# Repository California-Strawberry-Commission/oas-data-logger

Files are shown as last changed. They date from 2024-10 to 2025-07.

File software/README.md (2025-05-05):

# Operator Aid Systems Data Collection

## Objective

A common, fast and reliable method for data collection for Operator Aid Systems, such as bug vac and spray rig.

We continuously gather data from connected sensors, and save it to an SD card. When connected to WiFi, the data is uploaded to a server. We provide a web-based interface to visualize the data.

## Hardware

The [Adafruit ItsyBitsy ESP32](https://learn.adafruit.com/adafruit-itsybitsy-esp32/overview) was ultimately selected due to its small form factor, relatively large number of GPIO pins, power management, Wi-Fi and Bluetooth capabilities, and I2C connector. We had originally worked with the Sparkfun Thing Plus. However, the ItsyBitsy has a smaller size, extra power management features, and better isolation between the VCC and battery rails. With the Sparkfun Thing Plus, we needed to mod in a better diode onto the board to get USB power detection to work, and found that GPS did not work on I2C (and thus had to use UART).

Relevant features include:

- USB to serial converter chip
- Power regulator
- STEMMA QT I2C connector (which we use for the GPS module)
- Low power (light sleep at 4mA, deep sleep at ~10uA)
- Wi-Fi and Bluetooth
- 20 GPIO pins
- SPI pins (which we use for the MicroSD module)
- User switch
- Small form factor

The GPS module provides support for GPS, GLONASS, GALILEO, and QZSS, providing updates at up to 10 Hz and with both UART and I2C interfaces.

## Software

### ESP32

`oas-logger` is a PlatformIO (IDE for embedded systems, based on VSCode) project for the ESP32 to log data from various attached sensors (currently only GPS) using the Arduino API. It depends on `dlflib`, which is used for writing and uploading log data.

### Server

`data-visualizer` is a Next.js app deployed on Vercel for uploading and visualizing OAS data. It depends on `dlflib-js`, which is used for parsing `.dlf` files, and so we use an npm workspace.

See [README.md](data-visualizer/README.md).

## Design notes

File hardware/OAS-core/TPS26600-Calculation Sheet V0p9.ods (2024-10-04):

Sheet: Calculation Sheet
TPS26600 Design Calculation Tool
Constants Cells | Input/SelectCells | Calculation Cells
 | Calculated, but can be over-ridden by user
Parameter | Description | Value | Units | Tolerance
VIN (max) | Maximum System Input Voltage | 28.00 | V
Uvset | Undervoltage Lockout Threshold | 8.00 | V
OVset | Over Voltage Cut-Off Threshold | 29.00 | V
Cout | Load Capacitance | 220.0 | µF | 10%
TA (max) | Max Ambient Temperature | 85 | °C
RLstart | Load at start-up (assumed to be resistive) | 48.0 | Ω
Imax | Maximum continuous load current | 1.5 | A
ILimit | Current Limit, 20% higher than maximum continuous load current | 1.80 | A
UVLO, OVP Calculations
R3_sel | Select a value in the range from 10k to 49.9k | 10.0 | kΩ | 1% |  |  | 100
R2_cal | Calculated value of Resistor at UVLO pin | 26.3 | kΩ |  | 9.17 | Power Fail (VIN Falling) | 262.5
R1_cal | Calculated value of Resistor at IN pin | 207.4 | kΩ |  | 9.92 | UVLO (VIN Rising) | 207.4
SELECT THE VALUE OF RESISTORS AS CLOSEST AVAILABLE VALUE OF R2,R3 & R8 (refer schematics) |  |  |  |  | 29.75 | OV (VIN Rising)
R3_sel | Select the closest possible value as R3_cal | 10.00 | kΩ | 1% |  |  | 100
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

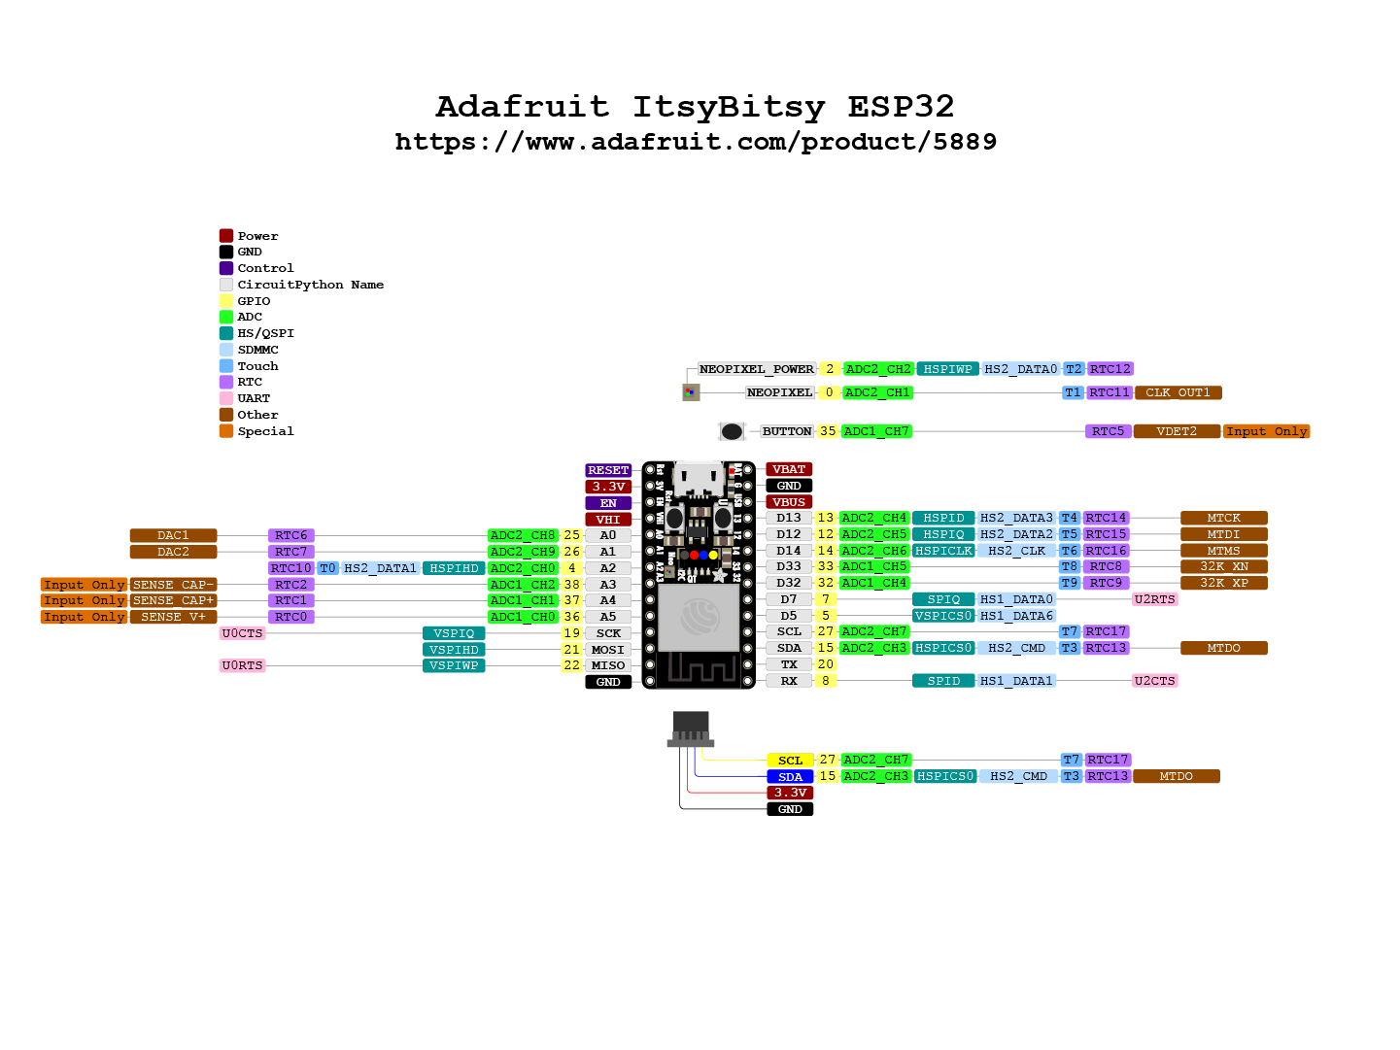
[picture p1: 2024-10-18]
hardware/prototype/adafruit_products_Adafruit_ItsyBitsy_ESP32_PrettyPinsPDF-100.jpg

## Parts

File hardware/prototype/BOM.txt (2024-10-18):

Cart		https://www.digikey.com/short/8qz30pnn

ESP32 		https://www.adafruit.com/product/5889
SD breakout	https://www.adafruit.com/product/4682
Battery		https://www.adafruit.com/product/2750
GPS		https://www.adafruit.com/product/4415
Qwicc conn. 	https://www.adafruit.com/product/4399

Battery Conn.	https://www.digikey.com/en/products/detail/adafruit-industries-llc/2750/6612470

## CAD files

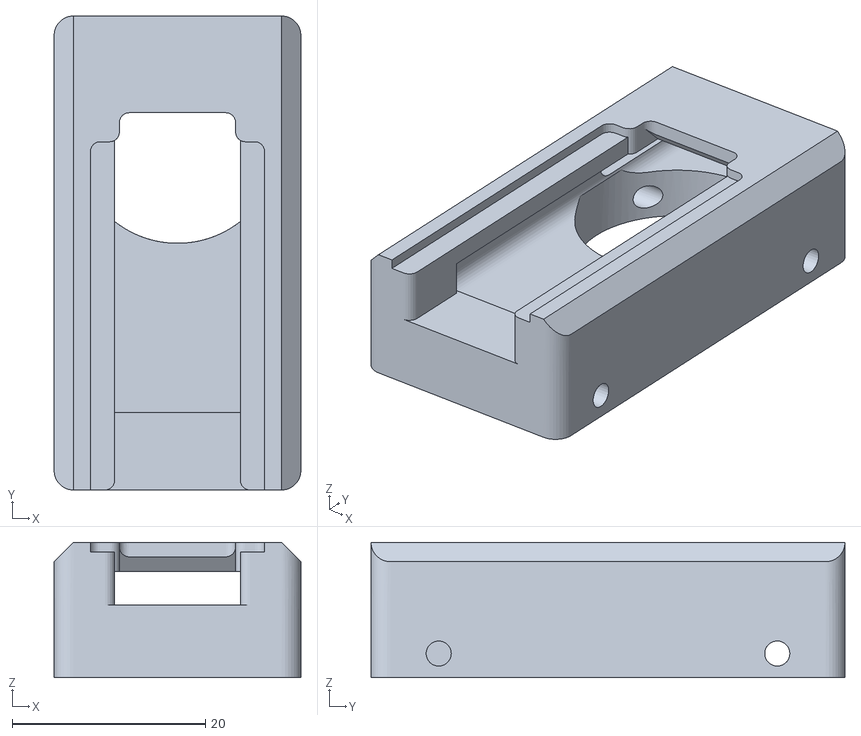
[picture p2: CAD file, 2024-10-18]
hardware/prototype/Carrier.stl
25.5 x 49.0 x 14.0

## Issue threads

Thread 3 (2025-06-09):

Automatically go back to sleep after sync complete

genkikondo, 2025-06-09:
Currently, when the device enters offload mode, it will stay on until either 1) the sleep button is pressed; 2) the reset button is pressed; or 3) the battery runs out. We want the device to go to sleep after syncing is complete, as there is nothing left to do afterwards.

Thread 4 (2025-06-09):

Ensure power draw is minimal in sleep mode

genkikondo, 2025-06-09:
Currently, peripherals (SD card module, GPS module) still draw power even in "deep sleep" mode.
90mA in normal mode (41.4mA without GPS)
80mA in deep sleep mode (31.2mA without GPS - due to MicroSD breakout board)
Figure out how to Ideally we can stay below 1mA in deep sleep mode.

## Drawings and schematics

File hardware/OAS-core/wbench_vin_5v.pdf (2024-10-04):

## WEBENCH ® Design Report

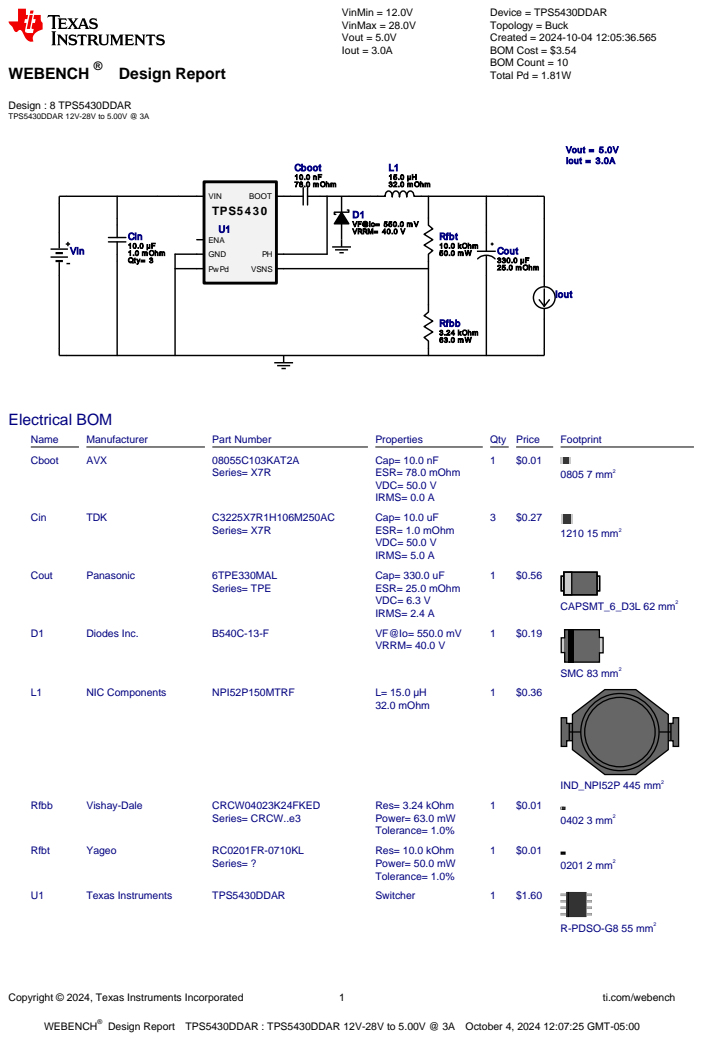
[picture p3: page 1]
Copyright © 2024, Texas Instruments Incorporated; ti.com/webench; WEBENCH®; Design : 8 TPS5430DDAR TPS5430DDAR 12V-28V to 5.00V @ 3A; VinMin = 12.0V VinMax = 28.0V Vout = 5.0V Iout = 3.0A; Device = TPS5430DDAR Topology = Buck Created = 2024-10-04 12:05:36.565 BOM Cost = $3.54 BOM Count = 10 Total Pd = 1.81W; Cboot 10.0 nF 78.0 m Ohm; Cin 10.0 µF 1.0 m Ohm Qty= 3; D1 VF@Io= 550.0 m V VRRM= 40.0 V; L1 15.0 µH 32.0 m Ohm; Rfbb 3.24 kOhm 63.0 m W; Rfbt 10.0 kOhm 50.0 m W; TPS5 4 3 0; ENA; GND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

Design Report TPS5430DDAR : TPS5430DDAR 12V-28V to 5.00V @ 3A October 4, 2024 12:07:25 GMT-05:00

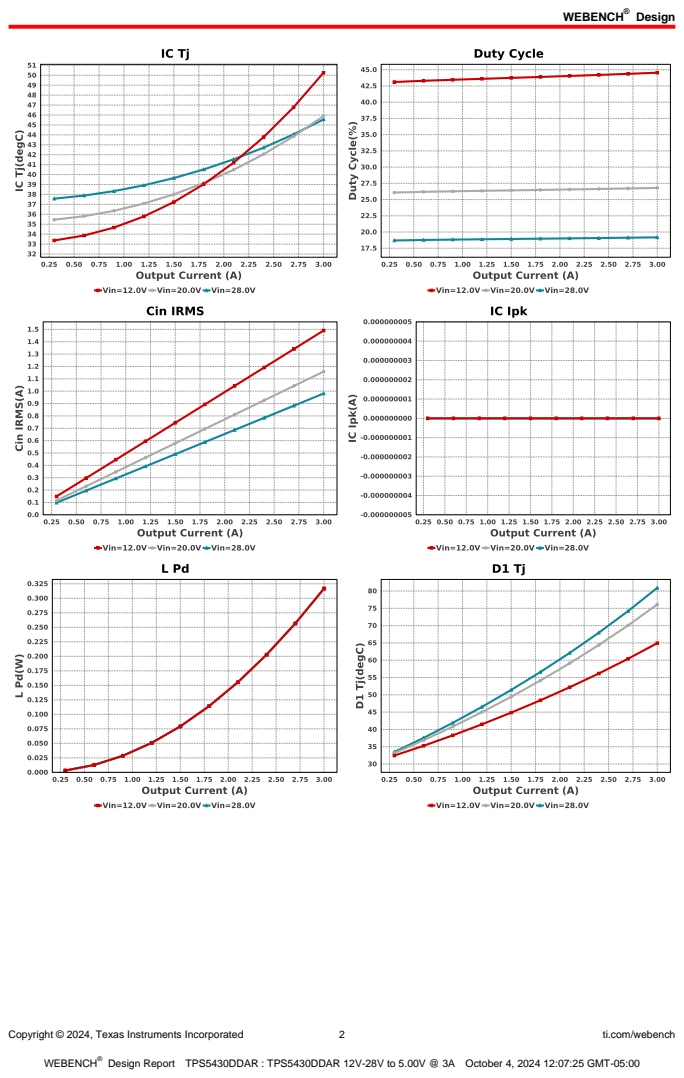
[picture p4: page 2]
Design; Copyright © 2024, Texas Instruments Incorporated; ti.com/webench

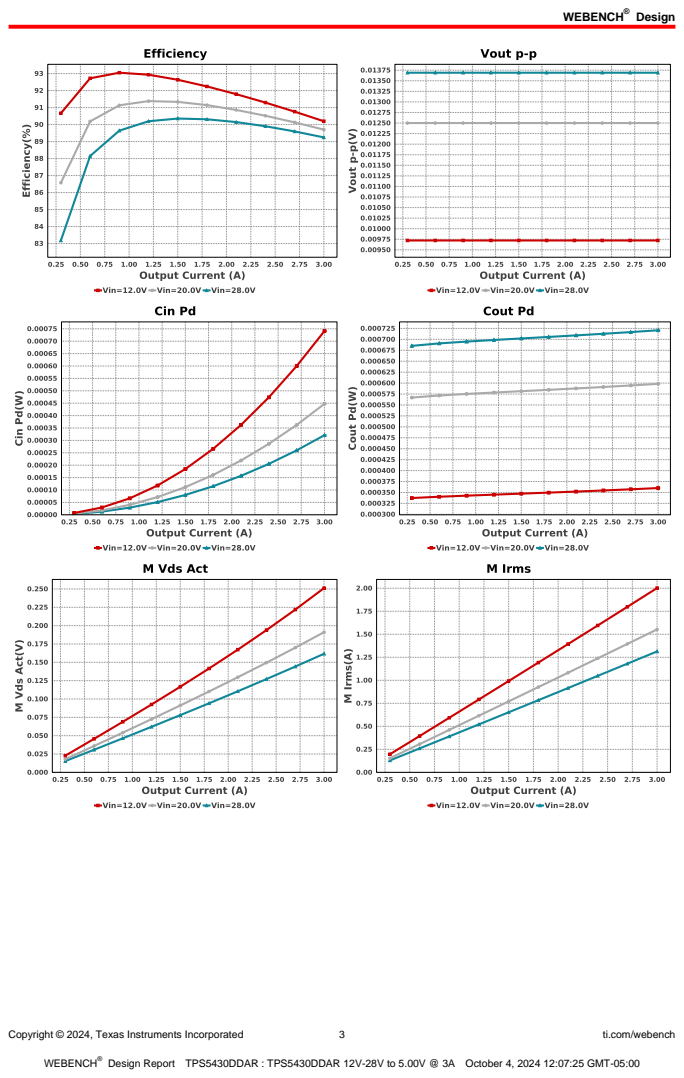
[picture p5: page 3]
Copyright © 2024, Texas Instruments Incorporated; ti.com/webench

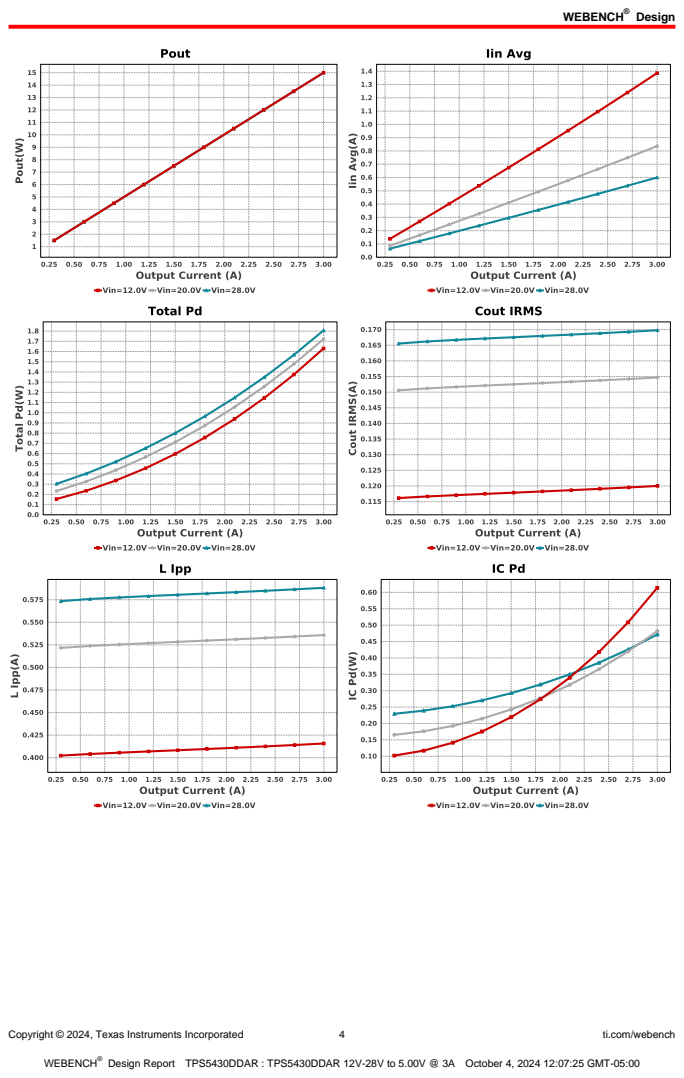
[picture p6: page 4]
Copyright © 2024, Texas Instruments Incorporated; ti.com/webench

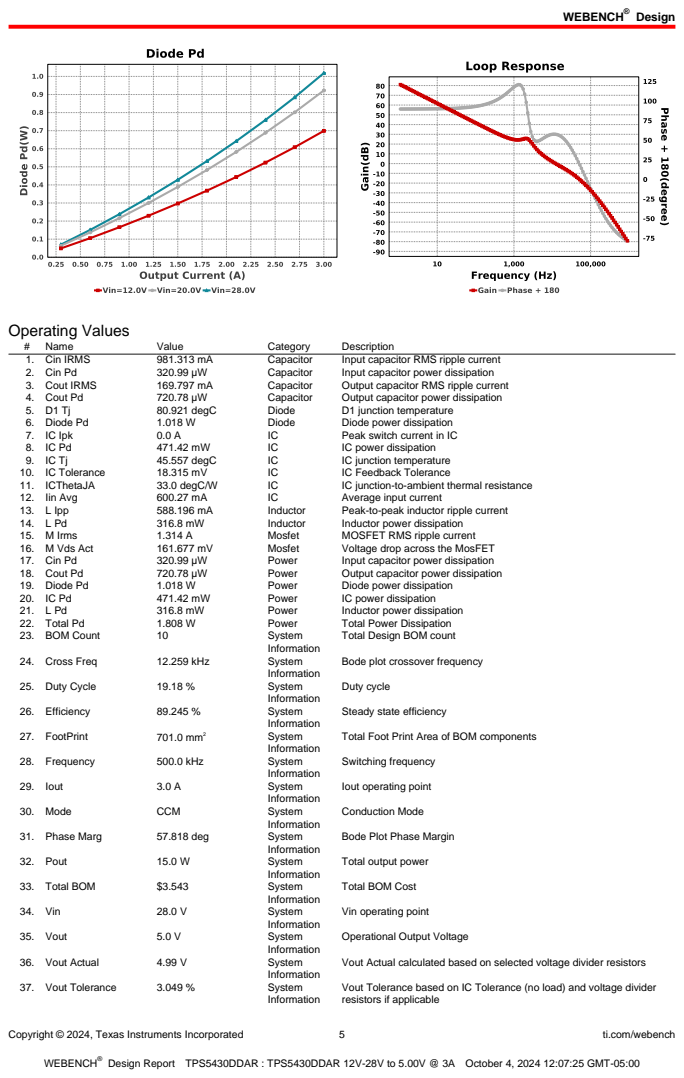
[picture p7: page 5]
Copyright © 2024, Texas Instruments Incorporated; ti.com/webench; Operating Values; Name; Value; Category; Description; 1. Cin IRMS; Capacitor; Input capacitor RMS ripple current; 2. Cin Pd; Input capacitor power dissipation; 3. Cout IRMS; Output capacitor RMS ripple current; 4. Cout Pd; Output capacitor power dissipation; 80.921 degC; Diode; D1 junction temperature; 6. Diode Pd; Diode power dissipation; 7. IC Ipk; Peak switch current in IC; IC power dissipation; 45.557 degC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

Total Design BOM count

Bode plot crossover frequency

Steady state efficiency

Total Foot Print Area of BOM components

Iout operating point

Bode Plot Phase Margin

Total output power

Total BOM Cost

Vin operating point

Operational Output Voltage

Vout Actual calculated based on selected voltage divider resistors

Vout Tolerance based on IC Tolerance (no load) and voltage divider
resistors if applicable

Copyright © 2024, Texas Instruments Incorporated | 6 | ti.com/webench
# | Name | Value | Category | Description

38. Vout p-p | 13.69 mV | System
| | | Information | Peak-to-peak output ripple voltage

## Design Inputs

Name | Value | Description
Iout | 3.0 | Maximum Output Current
VinMax | 28.0 | Maximum input voltage
VinMin | 12.0 | Minimum input voltage
Vout | 5.0 | Output Voltage
| base_pn | | TPS5430 | Base Product Number
source | DC | Input Source Type
Ta | 30.0 | Ambient temperature


Copyright © 2024, Texas Instruments Incorporated | 7 | ti.com/webench

## Assembly

## Component Testing

Some published data on components in datasheets such as Capacitor ESR and Inductor DC resistance is based on conservative values that will guarantee that the components always exceed the specification. For design purposes it is usually better to work with typical values. Since this data is not always available it is a good practice to measure the Capacitance and ESR values of Cin and Cout, and the inductance and DC resistance of L1 before assembly of the board. Any large discrepancies in values should be electrically simulated in WEBENCH to check for instabilities and thermally simulated in WebTHERM to make sure critical temperatures are not exceeded.

## Soldering Component to Board

If board assembly is done in house it is best to tack down one terminal of a component on the board then solder the other terminal. For surface mount parts with large tabs, such as the DPAK, the tab on the back of the package should be pre-tinned with solder, then tacked into place by one of the pins. To solder the tab town to the board place the iron down on the board while resting against the tab, heating both surfaces simultaneously. Apply light pressure to the top of the plastic case until the solder flows around the part and the part is flush with the PCB. If the solder is not flowing around the board you may need a higher wattage iron (generally 25W to 30W is enough).
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

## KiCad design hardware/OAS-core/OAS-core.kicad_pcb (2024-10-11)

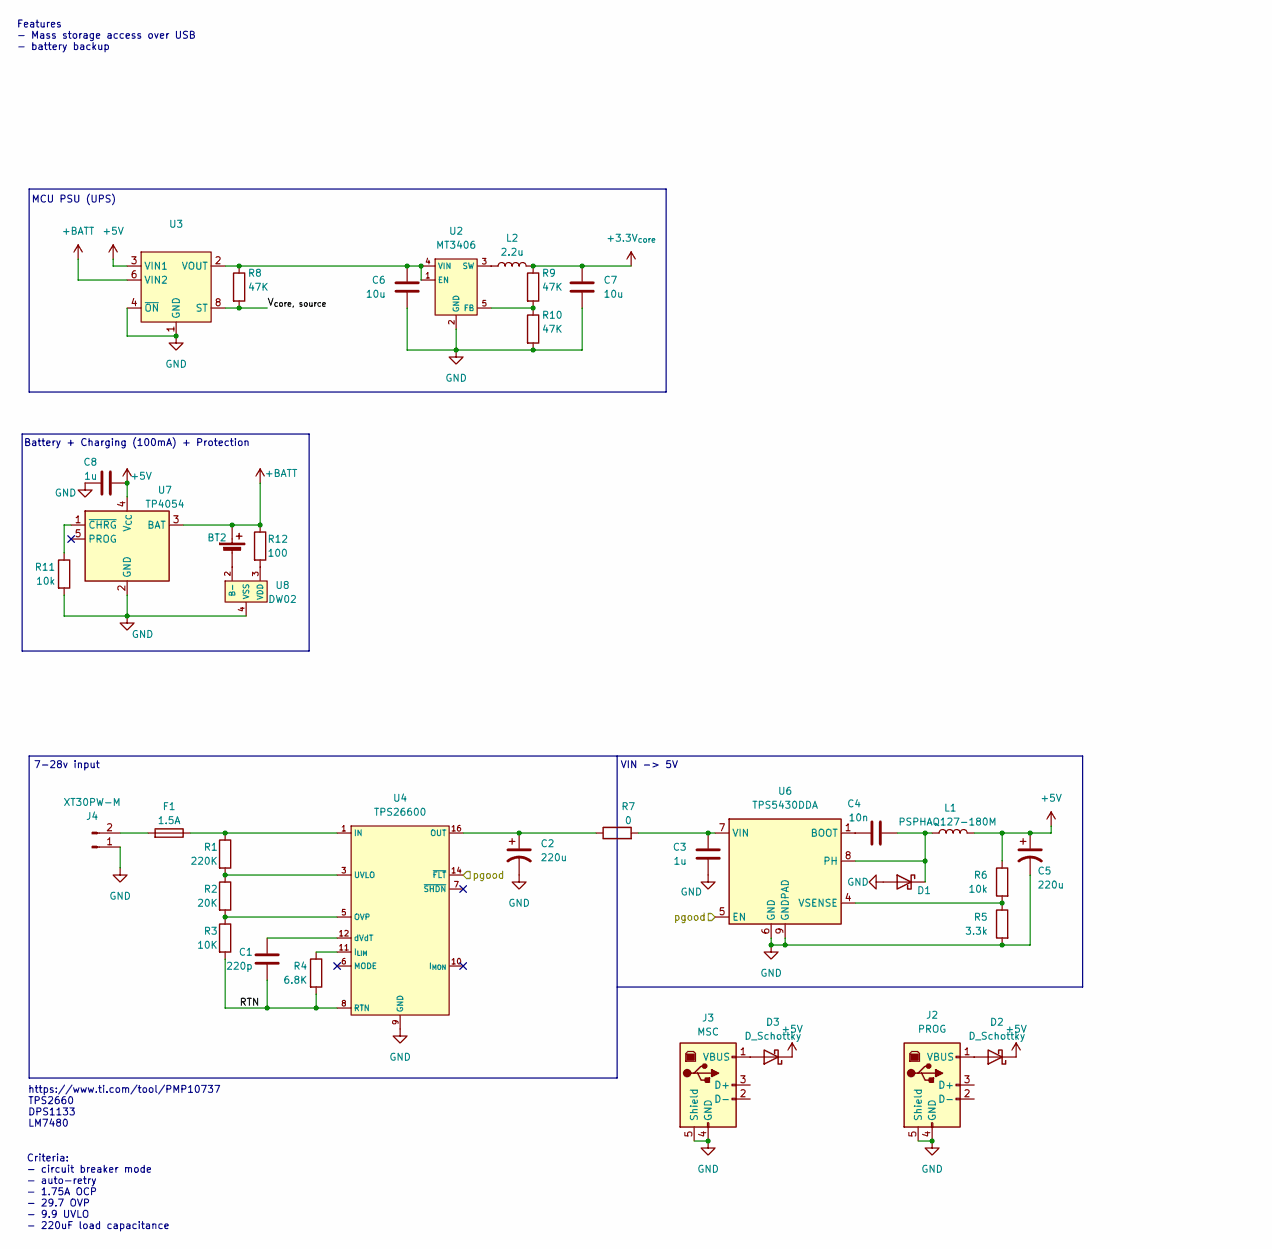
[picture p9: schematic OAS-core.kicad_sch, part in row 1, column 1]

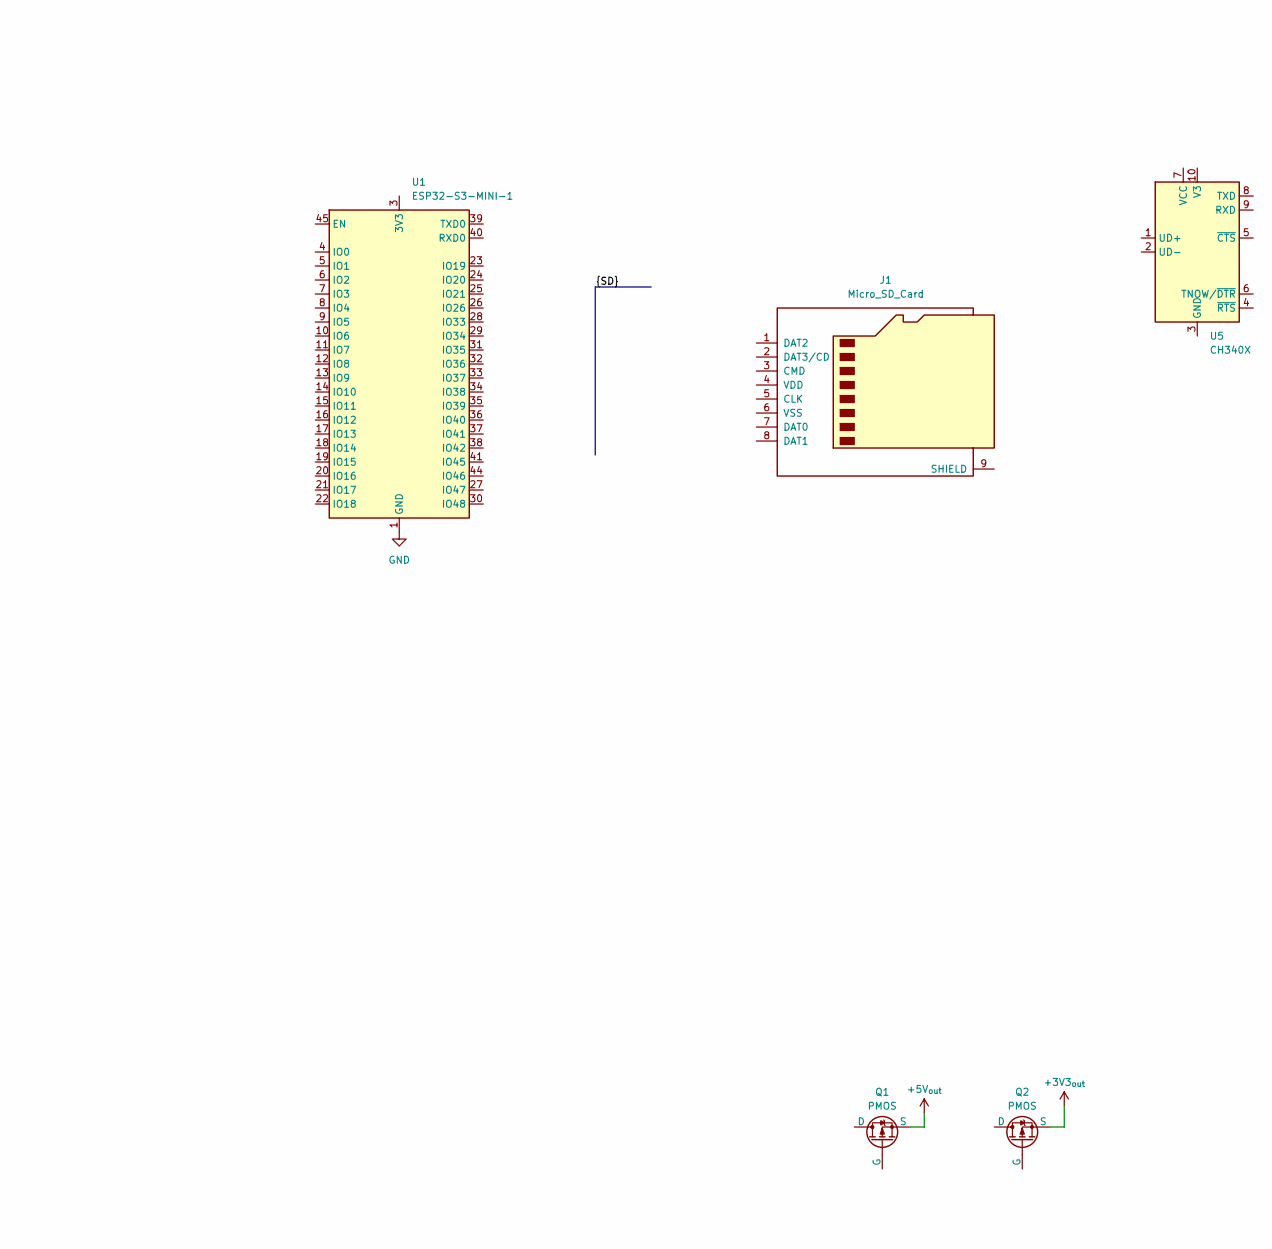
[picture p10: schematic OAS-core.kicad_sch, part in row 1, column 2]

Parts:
BT2: Battery_Cell; JST_PH_B2B-PH-SM4-TB_1x02-1MP_P2.00mm_Vertical
C1: 220p; C_0402_1005Metric
C2: 220u; CP_Elec_8x10.5; LCSC C2983323
C3, C8: 1u; C_0402_1005Metric
C4: 10n; C_0402_1005Metric
C5: 220u; CP_Elec_6.3x5.9; LCSC C2939793
C6, C7: 10u; C_0805_2012Metric; LCSC C15850
D1: D_Schottky; D_SMA; LCSC C7420369
D2, D3: D_Schottky
F1: 1.5A; R_0603_1608Metric; LCSC C2924957
J1: Micro_SD_Card; microSD_HC_Hirose_DM3AT-SF-PEJM5; LCSC C114218
J2: PROG; USB_B_OST_USB-B1HSxx_Horizontal
J3: MSC; USB_B_OST_USB-B1HSxx_Horizontal
J4: XT30PW-M; AMASS_XT30PW-M_1x02_P2.50mm_Horizontal
L1: PSPHAQ127-180M; L_12x12mm_H8mm; LCSC C2983064
L2: 2.2u; L_1008_2520Metric; LCSC C5156791
Q1, Q2: PMOS
R1: 220K; R_0402_1005Metric
R2: 20K; R_0402_1005Metric
R3: 10K; R_0402_1005Metric
R4: 6.8K; R_0402_1005Metric
R5: 3.3k; R_0402_1005Metric; LCSC C25890
R6, R11: 10k; R_0402_1005Metric
R7: 0; R_0402_1005Metric
R8, R9, R10: 47K; R_0402_1005Metric
R12: 100; R_0402_1005Metric
U1: ESP32-S3-MINI-1; ESP32-S2-MINI-1
U2: MT3406; SOT-23-5; LCSC C89358
U3: LM66200; SOT-583-8
U4: TPS26600; HTSSOP-16-1EP_4.4x5mm_P0.65mm_EP3.4x5mm_Mask2.46x2.31mm_The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
U5: CH340X; MSOP-10_3x3mm_P0.5mm
U6: TPS5430DDA; TI_SO-PowerPAD-8_ThermalVias; LCSC C9864
U7: TP4054; TSOT-23-5; LCSC C32574
U8: DW02; SOT-23-5; LCSC C7420470

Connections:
+3.3V_{core}: C7.1, L2.2, R9.1
+5V: C5.1, C8.1, D2.1 (K), D3.1 (K), L1.2, R6.1, U3.3 (VIN1), U7.4 (V_{CC})
+BATT: BT2.1 (+), R12.1, U3.6 (VIN2), U7.3 (BAT)
/RTN: C1.2, R3.2, R4.2, U4.8 (RTN), U4.17 (PAD)
/V_{core, source}: R8.2, U3.8 (ST)
/pgood: U4.14 (~FLT), U6.5 (EN)
GND: C2.2, C3.2, C5.2, C6.2, C7.2, C8.2, D1.2 (A), J2.4 (GND), J2.5 (Shield), J3.4 (GND), J3.5 (Shield), J4.1, R5.2, R10.2, R11.2, U1.1 (GND), U1.2 (GND), U1.42 (GND), U1.43 (GND), U1.46 (GND), U1.47 (GND), U1.48 (GND), U1.49 (GND), U1.50 (GND), U1.51 (GND), U1.52 (GND), U1.53 (GND), U1.54 (GND), U1.55 (GND), U1.56 (GND), U1.57 (GND), U1.58 (GND), U1.59 (GND), U1.60 (GND), U1.61 (GND), U1.62 (GND), U1.63 (GND), U1.64 (GND), U1.65 (GND), U2.2 (GND), U3.1 (GND), U3.4 (~ON), U3.5 (GND), U4.9 (GND), U6.6 (GND), U6.9 (GNDPAD), U7.2 (GND), U8.4 (VSS), U8.5 (VSS)
unnamed: BT2.2 (-), U8.2 (B-)
unnamed: C2.1, R7.1, U4.15 (OUT), U4.16 (OUT)
unnamed: C4.2, D1.1 (K), L1.1, U6.8 (PH)
unnamed: D2.2 (A), J2.1 (VBUS)
unnamed: D3.2 (A), J3.1 (VBUS)
unnamed: F1.1, R1.1, U4.1 (IN), U4.2 (IN)
unnamed: F1.2, J4.2
unnamed: C6.1, R8.1, U2.1 (EN), U2.4 (VIN), U3.2 (VOUT), U3.7 (VOUT)
unnamed: R9.2, R10.1, U2.5 (FB)
unnamed: L2.1, U2.3 (SW)
unnamed: R4.1, U4.11 (I_{LIM})
unnamed: R2.2, R3.1, U4.5 (OVP)
unnamed: R1.2, R2.1, U4.3 (UVLO)
unnamed: C1.1, U4.12 (dVdT)
unnamed: C4.1, U6.1 (BOOT)
unnamed: C3.1, R7.2, U6.7 (VIN)
unnamed: R5.1, R6.2, U6.4 (VSENSE)
unnamed: R11.1, U7.1 (~CHRG)
unnamed: R12.2, U8.3 (VDD)

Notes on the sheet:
VIN -> 5V
Criteria: - circuit breaker mode - auto-retry - 1.75A OCP - 29.7 OVP - 9.9 UVLO - 220uF load capacitance
Battery + Charging (100mA) + Protection
https://www.ti.com/tool/PMP10737 TPS2660 DPS1133 LM7480
7-28v input
MCU PSU (UPS)
Features - Mass storage access over USB - battery backup

Board: 2 copper layers, 37 parts (0 on the bottom side), 24 nets, no tracks yet.

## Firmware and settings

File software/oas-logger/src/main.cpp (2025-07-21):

#include <Arduino.h>
#include <ESP32Time.h>
#include <FastLED.h>
#include <SD.h>
#include <TinyGPSPlus.h>
#include <WiFi.h>
#include <WiFiManager.h>
#include <Wire.h>
#include <freertos/FreeRTOS.h>
#include <freertos/semphr.h>
#include <dlf_logger.h>

// Configuration
const int SERIAL_BAUD_RATE{115200};
const uint32_t LOGGER_MARK_AFTER_UPLOAD{100 * 1024};
const bool LOGGER_DELETE_AFTER_UPLOAD{false};
const bool WAIT_FOR_VALID_TIME{true};
const bool USE_LEGACY_GPIO_CONFIG{true};
const bool USB_POWER_OVERRIDE{false};
const bool USB_POWER_OVERRIDE_VALUE{true};
const int LOGGER_RUN_INTERVAL_S{0};
const int GPS_PRINT_INTERVAL_MS{1000};  

// Pin Definitions
const gpio_num_t PIN_USB_POWER{GPIO_NUM_13};
const gpio_num_t PIN_SLEEP_BUTTON{GPIO_NUM_35};
const gpio_num_t PIN_SD_SCK{USE_LEGACY_GPIO_CONFIG ? GPIO_NUM_8 : GPIO_NUM_19};
const gpio_num_t PIN_SD_MOSI{USE_LEGACY_GPIO_CONFIG ? GPIO_NUM_33 : GPIO_NUM_21};
const gpio_num_t PIN_SD_MISO{USE_LEGACY_GPIO_CONFIG ? GPIO_NUM_32 : GPIO_NUM_22};
const gpio_num_t PIN_SD_CS{GPIO_NUM_14};
const gpio_num_t PIN_GPS_WAKE{GPIO_NUM_5}; // CURRENTLY UNCONNECTED ON PROTOTYPE

// LED Configuration
#define LED_PIN PIN_NEOPIXEL
#define LED_TYPE WS2812
#define LED_COLOR_ORDER GRB
const int NUM_LEDS{1};
const uint8_t LED_BRIGHTNESS{10};

// GPS Configuration
const int I2C_ADDR_GPS{0x10};

// WiFi Configuration 
const char* WIFI_CONFIG_AP_NAME{"OASDataLogger"};
const int WIFI_CONNECT_ATTEMPT_INTERVAL_MS{10000};

// For server hosting
// 1. Uncomment lines below 
// 2. In uploader component, change to WifiClientSecure
const char* UPLOAD_HOST{"oas-data-logger.vercel.app"};
const uint16_t UPLOAD_PORT{443};

// For local hosting:
// 1. Uncomment the lines below
// 2. Go to uploader_component.cpp and change from WiFiClientSecure to WiFiClient.
//const char* UPLOAD_HOST{"192.168.1.129"};  // Your computer's local IP
//const uint16_t UPLOAD_PORT{3000};

// State Machine States
enum class SystemState {
  INIT,
  WAIT_SD,
  WAIT_WIFI,
  WAIT_GPS,
  WAIT_TIME,
  RUNNING,
  OFFLOAD,
  ERROR,
  SLEEP
};

// Error Types for LED Patterns
enum class ErrorType {
  NONE,
  SD_INIT_FAILED,
  GPS_NOT_RESPONDING,
  I2C_INIT_FAILED,
  WIFI_CONFIG_FAILED,
  LOGGER_INIT_FAILED
};

// Global Objects
CRGB leds[NUM_LEDS];
TinyGPSPlus gps;
ESP32Time rtc;
WiFiManager wifiManager;
CSCLogger logger{SD};
TaskHandle_t xGPS_Handle;

// State Machine Variables
SystemState currentState = SystemState::INIT;
ErrorType currentError = ErrorType::NONE;
bool offloadMode = false;
bool gpsEnabled = false;
run_handle_t runHandle{0};

// Timing Variables
unsigned long lastWifiReconnectAttemptMillis{0};
unsigned long lastLoggerStartRunMillis{0};
unsigned long lastLedToggleMillis{0};
unsigned long lastGpsPrintMillis{0};
bool ledToggleState = false;

// GPS Data Structure with Mutex Protection
struct GpsData {
  double lat;
  double lng;
  double alt;
  uint32_t satellites;
};

GpsData gpsData{0.0, 0.0, 0.0, 0};
SemaphoreHandle_t gpsDataMutex;

// Function Prototypes
void initializeLeds();
void updateLedPattern();
void transitionToState(SystemState newState);
void handleInitState();
void handleWaitSdState();
void handleWaitWifiState();
void handleWaitGpsState();
void handleWaitTimeState();
void handleRunningState();
void handleOffloadState();
void handleErrorState();
void handleSleepState();
bool hasUsbPower();
bool wifiCredentialsExist();
void enableGps();
void disableGps();
void initializeLogger();
void startLoggerRun();
void gpsTask(void* args);
void sleepMonitorTask(void* args);
void testNetworkConnectivity(void);

void setup() {
  Serial.begin(SERIAL_BAUD_RATE);
  
  // Initialize LED first for status indication
  initializeLeds();
  
  // Create mutex for GPS data protection
  gpsDataMutex = xSemaphoreCreateMutex();
  if (gpsDataMutex == NULL) {
    currentError = ErrorType::LOGGER_INIT_FAILED;
    transitionToState(SystemState::ERROR);
    return;
  }
  
  // Configure pins
  pinMode(PIN_USB_POWER, INPUT_PULLDOWN);
  pinMode(PIN_SLEEP_BUTTON, INPUT_PULLUP);
  pinMode(PIN_GPS_WAKE, OUTPUT);
  
  // Add delay to give time for serial to initialize
  vTaskDelay(pdMS_TO_TICKS(1000));
  
  // Start sleep monitor task
  xTaskCreate(sleepMonitorTask, "sleep_monitor", 4096, NULL, 5, NULL);
  
  // Determine initial mode based on USB power
  offloadMode = !hasUsbPower();
  
  // Start state machine
  transitionToState(SystemState::INIT);
}

void loop() {
  // Update LED pattern based on current state
  updateLedPattern();
  
  // State machine logic
  switch (currentState) {
    case SystemState::INIT:
      handleInitState();
      break;
    case SystemState::WAIT_SD:
      handleWaitSdState();
      break;
    case SystemState::WAIT_WIFI:
      handleWaitWifiState();
      break;
    case SystemState::WAIT_GPS:
      handleWaitGpsState();
      break;
    case SystemState::WAIT_TIME:
      handleWaitTimeState();
      break;
    case SystemState::RUNNING:
      handleRunningState();
      break;
    case SystemState::OFFLOAD:
      handleOffloadState();
      break;
    case SystemState::ERROR:
      handleErrorState();
      break;
    case SystemState::SLEEP:
      handleSleepState();
      break;
  }
  
  vTaskDelay(pdMS_TO_TICKS(10));
}

void initializeLeds() {
  FastLED.addLeds<LED_TYPE, LED_PIN, LED_COLOR_ORDER>(leds, NUM_LEDS);
  FastLED.setBrightness(LED_BRIGHTNESS);
  FastLED.showColor(CRGB::White);
}

void updateLedPattern() {
  unsigned long currentMillis = millis();
  
  switch (currentState) {
    case SystemState::INIT:
      FastLED.showColor(CRGB::White);
      break;
      
    case SystemState::WAIT_SD:
    case SystemState::WAIT_WIFI:
    case SystemState::WAIT_GPS:
    case SystemState::WAIT_TIME:
      // Yellow blinking for waiting states
      if (currentMillis - lastLedToggleMillis > 500) {
        lastLedToggleMillis = currentMillis;
        ledToggleState = !ledToggleState;
        FastLED.showColor(ledToggleState ? CRGB::Yellow : CRGB::Black);
      }
      break;
      
    case SystemState::RUNNING:
      FastLED.showColor(CRGB::Green);
      break;
      
    case SystemState::OFFLOAD:
      FastLED.showColor(CRGB::Blue);
      break;
      
    case SystemState::ERROR:
      // Different blink patterns for different errors
      uint32_t blinkInterval;
      switch (currentError) {
        case ErrorType::SD_INIT_FAILED:
          blinkInterval = 200; // Fast blink
          break;
        case ErrorType::GPS_NOT_RESPONDING:
          blinkInterval = 400; // Medium blink
          break;
        case ErrorType::I2C_INIT_FAILED:
          blinkInterval = 600; // Slow blink
          break;
        case ErrorType::WIFI_CONFIG_FAILED:
          blinkInterval = 800; // Very slow blink
          break;
        default:
          blinkInterval = 1000; // Default slow blink
          break;
      }
      
      if (currentMillis - lastLedToggleMillis > blinkInterval) {
        lastLedToggleMillis = currentMillis;
        ledToggleState = !ledToggleState;
        FastLED.showColor(ledToggleState ? CRGB::Red : CRGB::Black);
      }
      break;
      
    case SystemState::SLEEP:
      FastLED.showColor(CRGB::Black);
      break;
  }
}

void transitionToState(SystemState newState) {
  Serial.printf("State transition: %d -> %d\n", (int)currentState, (int)newState);
  currentState = newState;
  
  // Reset LED toggle state on transition
  ledToggleState = false;
  lastLedToggleMillis = millis();
}

void handleInitState() {
  if (offloadMode) {
    transitionToState(SystemState::WAIT_SD);
  } else {
    transitionToState(SystemState::WAIT_SD);
  }
}

void handleWaitSdState() {
  Serial.println("Initializing SPI for SD card...");

  SPI.setFrequency(1000000);
  SPI.setDataMode(SPI_MODE0);

  SPI.begin(PIN_SD_SCK, PIN_SD_MISO, PIN_SD_MOSI, PIN_SD_CS); // No return value to check

  if (SD.begin(PIN_SD_CS)) {
    Serial.println("SD card connected");
    transitionToState(SystemState::WAIT_WIFI);
  }

  // Keep trying, no immediate error transition
}

void handleWaitWifiState() {
  Serial.println("Initializing WiFi...");
  WiFi.mode(WIFI_STA);
  wifiManager.setConfigPortalBlocking(true);

  bool hasCreds = wifiCredentialsExist();

  if (offloadMode) {
    if (hasCreds) {
      Serial.println("Offload mode with credentials, attempting to connect indefinitely...");
      WiFi.begin();
      while (WiFi.status() != WL_CONNECTED) {
        Serial.println("Waiting for WiFi (offload mode)...");
        delay(1000);
      }
      Serial.println("Connected to WiFi.");
      testNetworkConnectivity();
      transitionToState(SystemState::OFFLOAD);
    } else {
      Serial.println("Offload mode with no credentials, entering AP mode indefinitely...");
      wifiManager.setConfigPortalTimeout(0); // Block until credentials provided
      if (!wifiManager.autoConnect(WIFI_CONFIG_AP_NAME)) {
        currentError = ErrorType::WIFI_CONFIG_FAILED;
        transitionToState(SystemState::ERROR);
        return;
      }
      Serial.println("Credentials acquired in AP mode.");
      transitionToState(SystemState::OFFLOAD);
    }
  } else {
    if (hasCreds) {
      Serial.println("Normal mode with credentials, attempting connection...");
      WiFi.begin();
      unsigned long startAttempt = millis();
      while (WiFi.status() != WL_CONNECTED && millis() - startAttempt < 10000) {
        delay(500);
        Serial.print(".");
      }

      if (WiFi.status() == WL_CONNECTED) {
        Serial.println("\nConnected to WiFi.");
        testNetworkConnectivity();
        transitionToState(SystemState::WAIT_GPS);
      } else {
        Serial.println("\nConnection failed, entering AP mode for 3 minutes...");
        wifiManager.setConfigPortalTimeout(180); // 3 minutes
        wifiManager.startConfigPortal(WIFI_CONFIG_AP_NAME);
        Serial.println("Exiting AP mode (timeout or user finished). Continuing program.");
        transitionToState(SystemState::WAIT_GPS); // Proceed regardless of connection
      }
    } else {
      Serial.println("No credentials, waiting in AP mode until provided...");
      wifiManager.setConfigPortalTimeout(0); // No timeout
      if (!wifiManager.autoConnect(WIFI_CONFIG_AP_NAME)) {
        currentError = ErrorType::WIFI_CONFIG_FAILED;
        transitionToState(SystemState::ERROR);
        return;
      }
      Serial.println("Credentials acquired in AP mode.");
      transitionToState(SystemState::WAIT_GPS);
    }
  }

  if (WiFi.status() == WL_CONNECTED) {
    testNetworkConnectivity();
  }
}

void handleWaitGpsState() {
  if (offloadMode) {
    // Skip GPS in offload mode
    transitionToState(SystemState::OFFLOAD);
    return;
  }
  
  enableGps();
  
  if (gpsEnabled) {
    // Start GPS task
    xTaskCreate(gpsTask, "gps", 4096, NULL, 5, &xGPS_Handle);
    transitionToState(SystemState::WAIT_TIME);
  }
}

void handleWaitTimeState() {
  // Try to get GPS data with mutex protection
  if (xSemaphoreTake(gpsDataMutex, portMAX_DELAY) == pdTRUE) {
    // Check if we have valid time
    if (gps.date.isUpdated() && gps.date.isValid() && 
        gps.time.isUpdated() && gps.time.isValid() && 
        gps.location.age() < 2000 && gps.date.year() >= 2025) {
      
      rtc.setTime(gps.time.second(), gps.time.minute(), gps.time.hour(),
                  gps.date.day(), gps.date.month(), gps.date.year());
      Serial.println("Valid time received");
      
      xSemaphoreGive(gpsDataMutex);
      
      // Initialize logger and start run
      initializeLogger();
      startLoggerRun();
      transitionToState(SystemState::RUNNING);
    } else {
      xSemaphoreGive(gpsDataMutex);
    }
  }
}

void handleRunningState() {
  // WiFi reconnection logic
  if (millis() - lastWifiReconnectAttemptMillis > WIFI_CONNECT_ATTEMPT_INTERVAL_MS) {
    if (WiFi.status() != WL_CONNECTED) {
      Serial.println("WiFi not connected, retrying...");
      WiFi.begin();
      lastWifiReconnectAttemptMillis = millis();
    } else {
      // Upload the current run over wifi
      static unsigned long lastUploadAttemptMillis = 0;
      const unsigned long UPLOAD_ATTEMPT_INTERVAL_MS = 30000; // Try upload every 30s when connected
      
      if (millis() - lastUploadAttemptMillis > UPLOAD_ATTEMPT_INTERVAL_MS) {
        lastUploadAttemptMillis = millis();
        
        if (runHandle) {
          // Get the current run directory name
          // The run name format appears to be based on when start_run was called
          // We need to access the logger's current run directory
          
          Serial.println("[Running State] Attempting to upload current run while logging...");

          UploaderComponent::Options tempOptions;
          tempOptions.deleteAfterUpload = false;
          tempOptions.markAfterUpload = false;
          
          // Create a temporary uploader instance for the current run
          UploaderComponent tempUploader(SD, "/", UPLOAD_HOST, UPLOAD_PORT, tempOptions);
          
          // The logger stores runs in the root directory with a specific naming convention
          // We need to find the current run directory
          File root = SD.open("/");
          if (root) {
            File runDir;
            String currentRunPath;
            
            // Find the most recent run directory (which should be our current run)
            // Run directories don't have the lockfile when complete, but our current run
            // should still have it
            while (runDir = root.openNextFile()) {
              if (runDir.isDirectory() && runDir.name()[0] != '.' &&
                  strcmp(runDir.name(), "System Volume Information") != 0) {
                
                // Check if this directory has a lockfile (indicating active run)
                File lockCheck = SD.open(String("/") + runDir.name() + "/" + LOCKFILE_NAME);
                if (lockCheck) {

                  lockCheck.close();
                  currentRunPath = String("/") + runDir.name();
                  Serial.printf("[Running State] Found active run: %s\n", runDir.name());

                  Serial.println("[Running State] Flushing data and finalizing headers for upload...");
                  logger.flush(runHandle); 

                  // Upload this run
                  String uploadPath = String("/api/upload/") + runDir.name();
                  bool uploadSuccess = tempUploader.uploadRun(runDir, uploadPath);

                  if (uploadSuccess) {
                    Serial.println("[Running State] Successfully uploaded current run data");
                    // Note: We don't mark or delete the run since it's still active
                  } else {
                    Serial.println("[Running State] Failed to upload current run data");
                  }
                  
                  break; // We found and processed the current run
                }
              }
            }
            root.close();
          }
        }
      }
    } 
  }
  
  // GPS printing logic - independent of logger run interval
  if (millis() - lastGpsPrintMillis > GPS_PRINT_INTERVAL_MS) {
    lastGpsPrintMillis = millis();
    
    // Try to get GPS data with mutex protection
    if (xSemaphoreTake(gpsDataMutex, pdMS_TO_TICKS(100)) == pdTRUE) {
      Serial.printf("[GPS] Lat: %.6f, Lng: %.6f, Alt: %.1fm, Sats: %d\n", 
                    gpsData.lat, gpsData.lng, gpsData.alt, gpsData.satellites);
      xSemaphoreGive(gpsDataMutex);
    }
  }
  
  // Run interval logic - only if LOGGER_RUN_INTERVAL_S > 0
  if (runHandle && LOGGER_RUN_INTERVAL_S > 0 &&
      millis() - lastLoggerStartRunMillis > LOGGER_RUN_INTERVAL_S * 1000) {
    startLoggerRun();
  }
}

void handleOffloadState() { 
  // Give logger sync/upload time to start
  vTaskDelay(pdMS_TO_TICKS(100));
  
  logger.waitForSyncCompletion();
  
  // After sync completion, either sleep or continue
  transitionToState(SystemState::SLEEP);
}

void handleErrorState() {
  // Error state is handled by LED pattern
  // Could add recovery logic here if needed
  
  // Log error details
  Serial.printf("System in ERROR state. Error type: %d\n", (int)currentError);
  
  // For critical errors, restart after 10 seconds
  static unsigned long errorStartMillis = millis();
  if (millis() - errorStartMillis > 10000) {
    ESP.restart();
  }
}

void handleSleepState() {
  Serial.println("Entering deep sleep...");
  
  // Stop all tasks
  disableGps();
  
  // Turn off LED
  FastLED.showColor(CRGB::Black);
  
  // Configure wake on USB power only if unconnected, else wake on reset.
  if (!hasUsbPower()) {
    esp_sleep_enable_ext0_wakeup(PIN_USB_POWER, 1);
  } else {
    esp_sleep_disable_wakeup_source(ESP_SLEEP_WAKEUP_ALL);
  }
  
  // Enter deep sleep
  esp_deep_sleep_start();
}

bool hasUsbPower() {
  if (USB_POWER_OVERRIDE) {
    return USB_POWER_OVERRIDE_VALUE;
  }
  return digitalRead(PIN_USB_POWER);
}

bool wifiCredentialsExist() {
  wifi_config_t conf;
  esp_err_t result = esp_wifi_get_config(WIFI_IF_STA, &conf);
  
  if (result != ESP_OK) {
    Serial.printf("esp_wifi_get_config failed: %d\n", result);
    return false;
  }
  
  return strlen((const char*)conf.sta.ssid) > 0;
}

void enableGps() {
  if (gpsEnabled) {
    return;
  }
  
  Serial.println("Enabling GPS...");
  
  // Initialize I2C
  if (!Wire.begin()) {
    currentError = ErrorType::I2C_INIT_FAILED;
    transitionToState(SystemState::ERROR);
    return;
  }
  
  // Activate wake pin
  digitalWrite(PIN_GPS_WAKE, HIGH);
  
  // Wait for GPS to respond
  bool gpsResponding = false;
  int attempts = 0;
  const int maxAttempts = 10;
  
  while (!gpsResponding && attempts < maxAttempts) {
    Wire.requestFrom(I2C_ADDR_GPS, 32);
    while (Wire.available()) {
      char c = Wire.read();
      gps.encode(c);
      gpsResponding = true;
    }
    
    if (!gpsResponding) {
      attempts++;
      vTaskDelay(pdMS_TO_TICKS(500));
    }
  }
  
  if (!gpsResponding) {
    currentError = ErrorType::GPS_NOT_RESPONDING;
    transitionToState(SystemState::ERROR);
    return;
  }
  
  digitalWrite(PIN_GPS_WAKE, LOW);
  gpsEnabled = true;
  Serial.println("GPS enabled");
}

void disableGps() {
  if (!gpsEnabled) {
    return;
  }
  
  Serial.println("Disabling GPS...");

  // Check if the task handle is valid
  if (gpsTask != NULL)
  {
      Serial.println("[GPS] Deleting GPS task...");
      // Delete the task
      vTaskDelete(xGPS_Handle);
  }
  
  // Put GPS in Backup Mode
  if (!USE_LEGACY_GPIO_CONFIG) {
    Wire.beginTransmission(I2C_ADDR_GPS);
    Wire.write("$PMTK225,4*2F\r\n");
    Wire.endTransmission();
  }
  
  // Close I2C
  Wire.end();
  
  gpsEnabled = false;
  Serial.println("GPS disabled");
}

void initializeLogger() {
  Serial.println("Initializing logger...");
  
  auto satellitesLogInterval{std::chrono::seconds(5)};
  POLL(logger, gpsData.satellites, satellitesLogInterval);
  
  auto gpsDataLogInterval{std::chrono::seconds(1)};
  POLL(logger, gpsData.lat, gpsDataLogInterval);
  POLL(logger, gpsData.lng, gpsDataLogInterval);
  POLL(logger, gpsData.alt, gpsDataLogInterval);
  
  UploaderComponent::Options options;
  options.markAfterUpload = LOGGER_MARK_AFTER_UPLOAD;
  options.deleteAfterUpload = LOGGER_DELETE_AFTER_UPLOAD;
  logger.syncTo(UPLOAD_HOST, UPLOAD_PORT, options).begin();
  
  Serial.println("Logger initialized");
}

void startLoggerRun() {
  if (runHandle) {
    logger.stop_run(runHandle);
  }
  
  double m = 0;
  runHandle = logger.start_run(Encodable(m, "double"));
  lastLoggerStartRunMillis = millis();
}

void gpsTask(void* args) {
  while (true) {
    // Request data from GPS
    Wire.requestFrom(I2C_ADDR_GPS, 32);
    
    // Process received data
    while (Wire.available()) {
      char c = Wire.read();
      gps.encode(c);
    }
    
    // Update GPS data with mutex protection
    if (xSemaphoreTake(gpsDataMutex, portMAX_DELAY) == pdTRUE) {
      // Make sure the data will be valid
      if (gps.satellites.isUpdated() && gps.satellites.isValid() && gps.satellites.value() != 0 ) {
        gpsData.satellites = gps.satellites.value();

        if (gps.location.isUpdated() && gps.location.isValid()) {
          gpsData.lat = gps.location.lat();
          gpsData.lng = gps.location.lng();
          gpsData.alt = gps.altitude.meters();
        }
      }
      xSemaphoreGive(gpsDataMutex);
    }
    
    vTaskDelay(pdMS_TO_TICKS(100));
  }
}

void sleepMonitorTask(void* args) {
  vTaskDelay(pdMS_TO_TICKS(5000));
  
  bool usbSleepTriggered = false;
  
  while (true) {
    // Only check sleep conditions if we're in RUNNING state
    if (currentState == SystemState::RUNNING) {
      // Check sleep button
      bool sleepButtonPressed = !digitalRead(PIN_SLEEP_BUTTON);
      if (sleepButtonPressed) {
        Serial.println("[Sleep Monitor] Sleep button pressed. Starting offload before sleep");
        
        // Stop current run before transitioning to offload
        if (runHandle) {
          logger.stop_run(runHandle);
          runHandle = 0;
        }
        
        transitionToState(SystemState::OFFLOAD);
        break;
      }
      
      // Check USB power for sleep trigger
      bool usbSleep = !offloadMode && !hasUsbPower();
      if (usbSleep && usbSleepTriggered) {
        Serial.println("[Sleep Monitor] USB power disconnected. Starting offload before sleep");
        
        // Stop current run before transitioning to offload
        if (runHandle) {
          logger.stop_run(runHandle);
          runHandle = 0;
        }
        
        transitionToState(SystemState::OFFLOAD);
        break;
      } else if (usbSleep) {
        usbSleepTriggered = true;
      } else {
        usbSleepTriggered = false;
      }
    }
    
    vTaskDelay(pdMS_TO_TICKS(1000));
  }
  
  // Task will be deleted when system enters sleep
  vTaskDelete(NULL);
}
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

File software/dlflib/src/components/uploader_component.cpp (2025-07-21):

#include "uploader_component.h"

#include <WiFiClientSecure.h>
#include <WiFiClient.h>

#include "dlf_cfg.h"
#include "dlf_logger.h"

UploaderComponent::UploaderComponent(FS &fs, String fsDir, String host,
                                     uint16_t port, const Options &options)
    : fs_(fs), dir_(fsDir), host_(host), port_(port), options_(options) {}

bool UploaderComponent::begin() {
  Serial.println("[UploaderComponent] begin");
  wifiEvent_ = xEventGroupCreate();
  syncEvent_ = xEventGroupCreate();

  // Initial states
  if (WiFi.status() == WL_CONNECTED) {
    xEventGroupSetBits(wifiEvent_, WLAN_READY);
  } else {
    xEventGroupClearBits(wifiEvent_, WLAN_READY);
  }
  xEventGroupSetBits(syncEvent_, SYNC_COMPLETE);

  // State change callbacks
  WiFi.onEvent(std::bind(&UploaderComponent::onWifiDisconnected, this,
                         std::placeholders::_1, std::placeholders::_2),
               ARDUINO_EVENT_WIFI_STA_DISCONNECTED);
  WiFi.onEvent(std::bind(&UploaderComponent::onWifiConnected, this,
                         std::placeholders::_1, std::placeholders::_2),
               ARDUINO_EVENT_WIFI_STA_GOT_IP);

  xTaskCreate(syncTask, "sync", 4096, this, 5, NULL);

  return true;
}

void UploaderComponent::onWifiDisconnected(arduino_event_id_t event,
                                           arduino_event_info_t info) {
  Serial.println("[UploaderComponent] WiFi disconnected");
  xEventGroupClearBits(wifiEvent_, WLAN_READY);
}

void UploaderComponent::onWifiConnected(arduino_event_id_t event,
                                        arduino_event_info_t info) {
  Serial.println("[UploaderComponent] WiFi connected");
  xEventGroupSetBits(wifiEvent_, WLAN_READY);
}

bool UploaderComponent::uploadRun(File runDir, String path) {
  //WiFiClient client; 
  WiFiClientSecure client;
  client.setInsecure();
  
  Serial.println("\n=== UPLOAD DEBUG INFO ===");
  Serial.printf("Host: %s\n", host_.c_str());
  Serial.printf("Port: %d\n", port_);
  Serial.printf("Path: %s\n", path.c_str());
  Serial.printf("URL: http://%s:%d%s\n", host_.c_str(), port_, path.c_str());

  if (!runDir) {
    Serial.println("[UploaderComponent] No file to upload");
    return false;
  }

  // List files to be uploaded
  Serial.println("Files to upload:");
  runDir.rewindDirectory();
  File tempFile;
  while (tempFile = runDir.openNextFile()) {
    Serial.printf("  - %s (%d bytes)\n", tempFile.name(), tempFile.size());
    tempFile.close();
  }

  // Try to connect
  Serial.printf("Attempting connection to %s:%d...\n", host_.c_str(), port_);
  
  for (int retries = 0; retries < 3; retries++) {
    if (client.connect(host_.c_str(), port_)) {
      Serial.println("Connected successfully!");
      break;
    }
    Serial.printf("Connection attempt %d failed. ", retries + 1);
    if (retries < 2) {
      Serial.println("Retrying in 1s...");
      vTaskDelay(pdMS_TO_TICKS(1000));
    }
  }

  if (!client.connected()) {
    Serial.println("[UploaderComponent] Failed to connect after 3 attempts.");
    return false;
  }

  // Create request
  // Note that we need to manually construct the multipart/form-data body, and
  // each file must be streamed (avoid fully loading into memory)
  const char *boundary = "dlfboundary";
  const char *boundaryTemplate =
      "--dlfboundary\r\n"
      "Content-Disposition: form-data; name=\"files\"; filename=\"%s\"\r\n"
      "Content-Type: application/octet-stream\r\n\r\n";
  const char *endBoundary = "--dlfboundary--\r\n";

  // First, calculate the content length (which needs to go into the request
  // header)
  size_t contentLength = 0;
  runDir.rewindDirectory();
  File file = runDir.openNextFile();
  while (file) {
    contentLength += snprintf(NULL, 0, boundaryTemplate, file.name());
    contentLength += file.size();
    contentLength += 2;  // for trailing \r\n after file content
    file.close();
    file = runDir.openNextFile();
  }
  contentLength += strlen(endBoundary);

  // Debug print out header information.
  Serial.println("\n=== HTTP REQUEST ===");
  Serial.printf("POST %s HTTP/1.1\r\n", path.c_str());
  Serial.printf("Host: %s\r\n", host_.c_str());
  Serial.printf("Content-Type: multipart/form-data; boundary=dlfboundary\r\n");
  Serial.printf("Content-Length: %zu\r\n", contentLength);
  Serial.println("Connection: close\r\n");
  Serial.println("===================\n");

  // Send POST request header
  Serial.println("[UploaderComponent] Sending upload request...");

  client.printf("POST %s HTTP/1.1\r\n", path.c_str());
  client.printf("Host: %s\r\n", host_.c_str());
  client.printf("Content-Type: multipart/form-data; boundary=%s\r\n", boundary);
  client.printf("Content-Length: %zu\r\n", contentLength);
  client.println("Connection: close\r\n");
  client.println();  // end of headers

  // Send boundaries and file data
  runDir.rewindDirectory();
  const size_t chunkSize = 128;
  uint8_t buf[chunkSize];
  file = runDir.openNextFile();
  while (file) {
    // Send boundary
    client.printf(boundaryTemplate, file.name());

    // Send file data
    while (file.available()) {
      size_t len = file.read(buf, chunkSize);
      client.write(buf, len);
    }
    client.print("\r\n");
    file.close();
    file = runDir.openNextFile();
  }
  client.print(endBoundary);

  // Wait for response
  unsigned long startMillis = millis();
  while (client.connected() && millis() - startMillis < 5000) {
    if (client.available()) {
      // We don't need to process the full response body, so return as soon as
      // we receive a line
      String statusLine = client.readStringUntil('\n');
      Serial.println("[UploaderComponent] Response: " + statusLine);
      client.stop();

      return statusLine.startsWith("HTTP/1.1 200") ||
             statusLine.startsWith("HTTP/1.0 200");
    }
  }

  Serial.println("[UploaderComponent] No response received within 5 seconds");
  client.stop();
  return false;
}

void UploaderComponent::waitForSyncCompletion() {
  xEventGroupWaitBits(syncEvent_, SYNC_COMPLETE, pdFALSE, pdTRUE,
                      portMAX_DELAY);
}
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

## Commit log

2024-10-02 Spec input protection
    [OAS-core.kicad_sch, vin_prot.kicad_sch]
2024-10-03 TPS2660 calcs
    [TPS26600-Calculation Sheet V0p9.ods]
2024-10-07 PSU Mux
    [OAS-core.kicad_sch, power_mux.kicad_sch]
2024-10-11 MCU PSU spec + impl
    [OAS-core.kicad_pcb, OAS-core.kicad_sch]
2024-10-18 Adapt code for prototype HW v2
    [Carrier.stl]
2025-04-14 [oas][v2][software] Wait until GPS starts sending data before deactivating wake pin
2025-04-24 [esp32] Wait until the GPS provides a valid time during initialization
2025-04-24 [js-lib] Don't track built files
2025-04-24 [demo] Add USB power override for testing
2025-05-01 [oas-logger] Implemented Access Point mode for configuring WiFi and properly skip upload of active run
    [dlf_logfile.cpp, dlf_run.cpp, main.cpp]
2025-05-01 [oas-logger][trivial] Add a couple of TODOs
2025-05-15 [oas-logger] Add option to use legacy GPIO pin configuration
2025-05-15 [oas-logger] Add an option to cut a run every X seconds
2025-05-15 [dlflib] Skip uploading already uploaded runs
    [main.cpp, uploader_component.cpp]
2025-06-10 [dlflib] Prevent potentially uploading incomplete run
    [dlf_run.cpp, uploader_component.cpp]
2025-07-02 updated readme, local databases set up but not yet functional due to networking errors
    [main.cpp]
2025-07-03 The problem: it is uploading no files
    [main.cpp, uploader_component.cpp]
2025-07-07 just doesn't visualize the data
    [main.cpp]
2025-07-17 added intermittent uploads to original prototype code

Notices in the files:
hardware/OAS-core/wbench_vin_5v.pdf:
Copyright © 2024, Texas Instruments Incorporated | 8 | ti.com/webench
